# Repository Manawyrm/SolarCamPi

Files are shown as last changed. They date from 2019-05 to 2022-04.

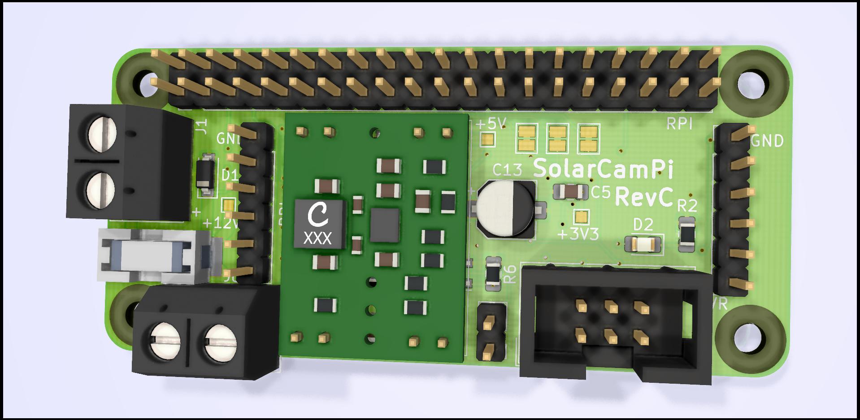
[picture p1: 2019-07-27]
pcb/solarcampi.jpg

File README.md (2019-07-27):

# SolarCamPi

__Detailed information at https://tbspace.de/solarcampi.html__

BOM (PCB-RevC):  
https://tbspace.de/content/downloads/ibom_solarcampi_revc.html

Firmware (PCB-RevB/RevC):  
https://github.com/Manawyrm/SolarCamPi/tree/master/firmware

Schematic (PCB-RevC):  
https://github.com/Manawyrm/SolarCamPi/blob/master/pcb/solarcampi.pdf

Raspberry Pi can flash the AVR, using [avrdude with LinuxSPI support](https://github.com/kcuzner/avrdude) and _inverted_ GPIO 17 as reset.

avrdude.conf configuration entry: 
```
programmer 
  id       = "linuxspi";
  desc     = "Use Linux SPI device in /dev/spidev*";
  type     = "linuxspi";
  reset    = ~ 17;
  baudrate = 40000;
;
```

avrdude Usage to flash firmware:  
`avrdude -p m328p -P /dev/spidev0.0 -c linuxspi -U flash:w:firmware.hex`
  
avrdude Usage to set fuses:  
`avrdude -p m328p -P /dev/spidev0.0 -c linuxspi -U lfuse:w:0xe2:m -U hfuse:w:0xd9:m -U efuse:w:0xfd:m`

Revision B PCB

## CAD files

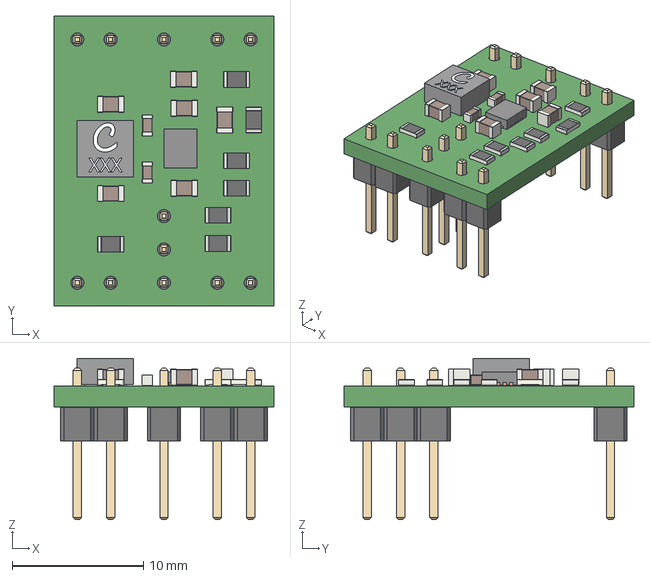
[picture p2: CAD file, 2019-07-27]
pcb/models/module-full.step
16.8 x 22.1 x 12.3 mm

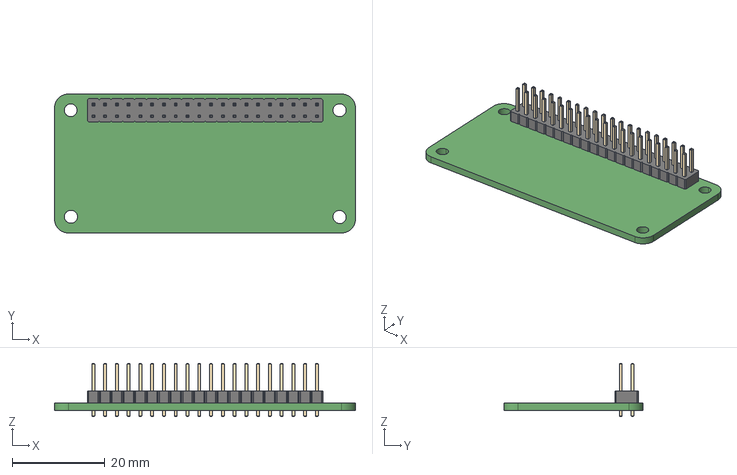
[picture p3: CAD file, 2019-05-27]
solarcampi/solarcampi.step
65.0 x 30.0 x 11.5 mm

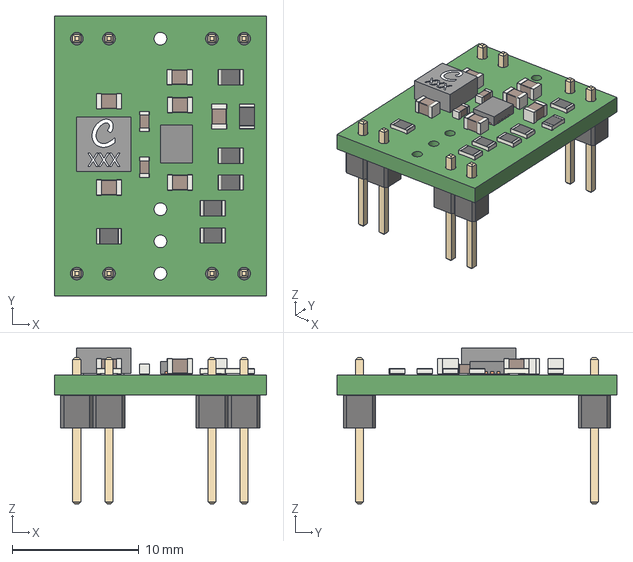
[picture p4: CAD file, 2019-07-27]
pcb/models/module-compat.step
16.8 x 22.1 x 12.3 mm

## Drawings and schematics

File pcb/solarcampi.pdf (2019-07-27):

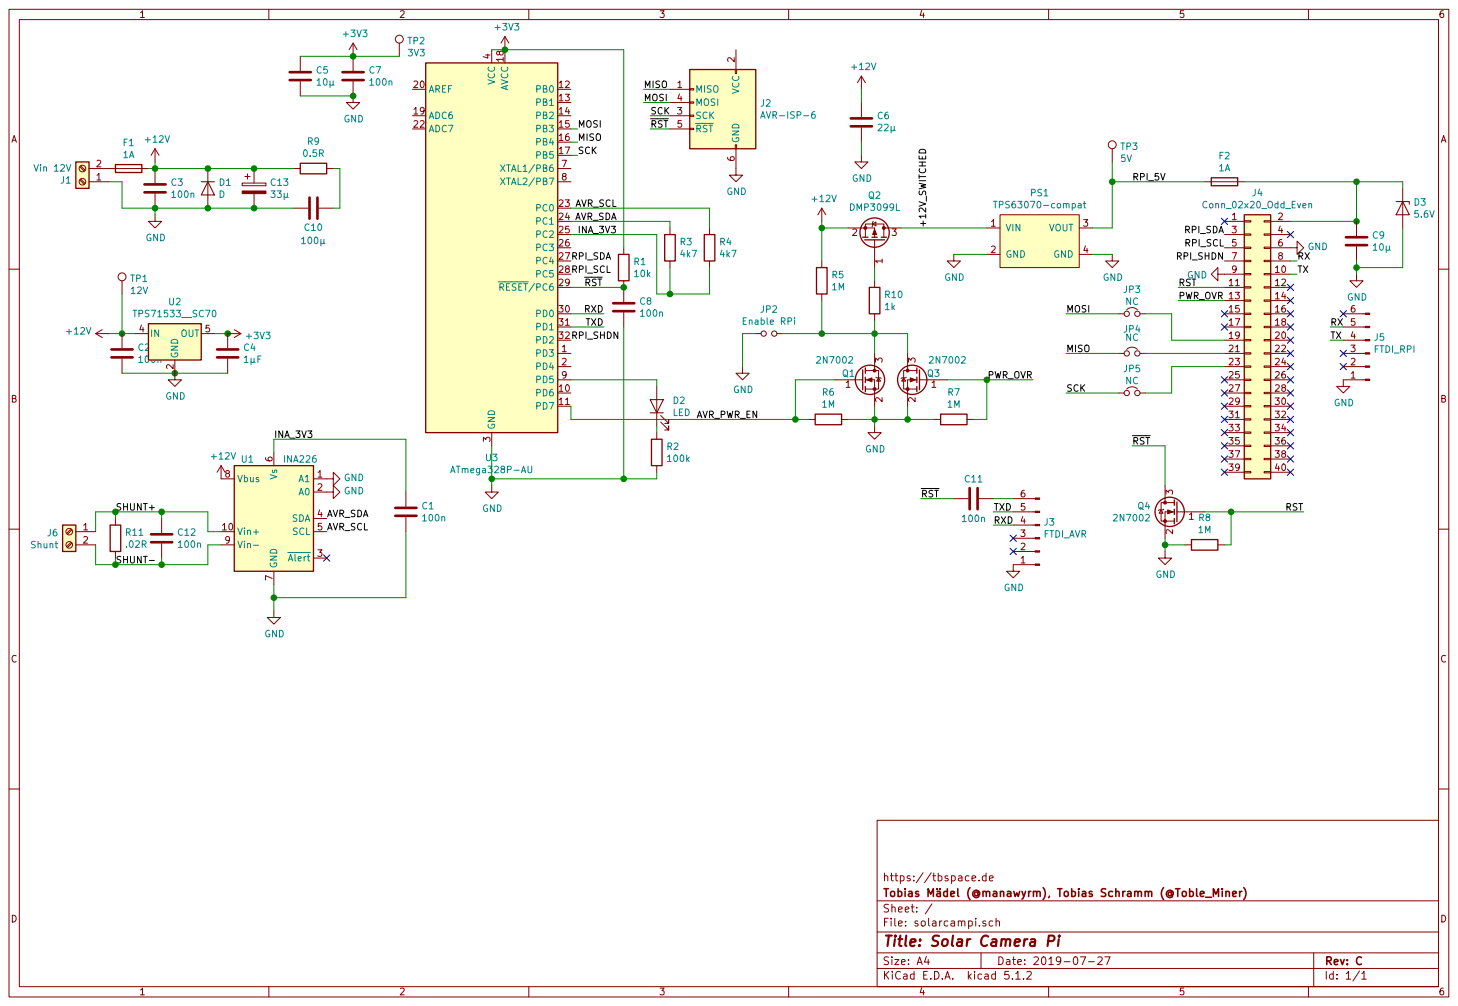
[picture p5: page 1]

2 SCK 3 MOSI 4 RST 5 GND
4k7GND

J2AVR-ISP-6 RST SCK MOSI MISO MOSI MISO

7 Vbus 8 Vin- 9 U1 INA226 SHUNT+ SHUNT- C12

https://tbspace.de
File: solarcampi.sch Sheet: / Tobias Mädel (@manawyrm), Tobias Schramm (@Toble_Miner)

Id: 1/1 Title: Solar Camera Pi

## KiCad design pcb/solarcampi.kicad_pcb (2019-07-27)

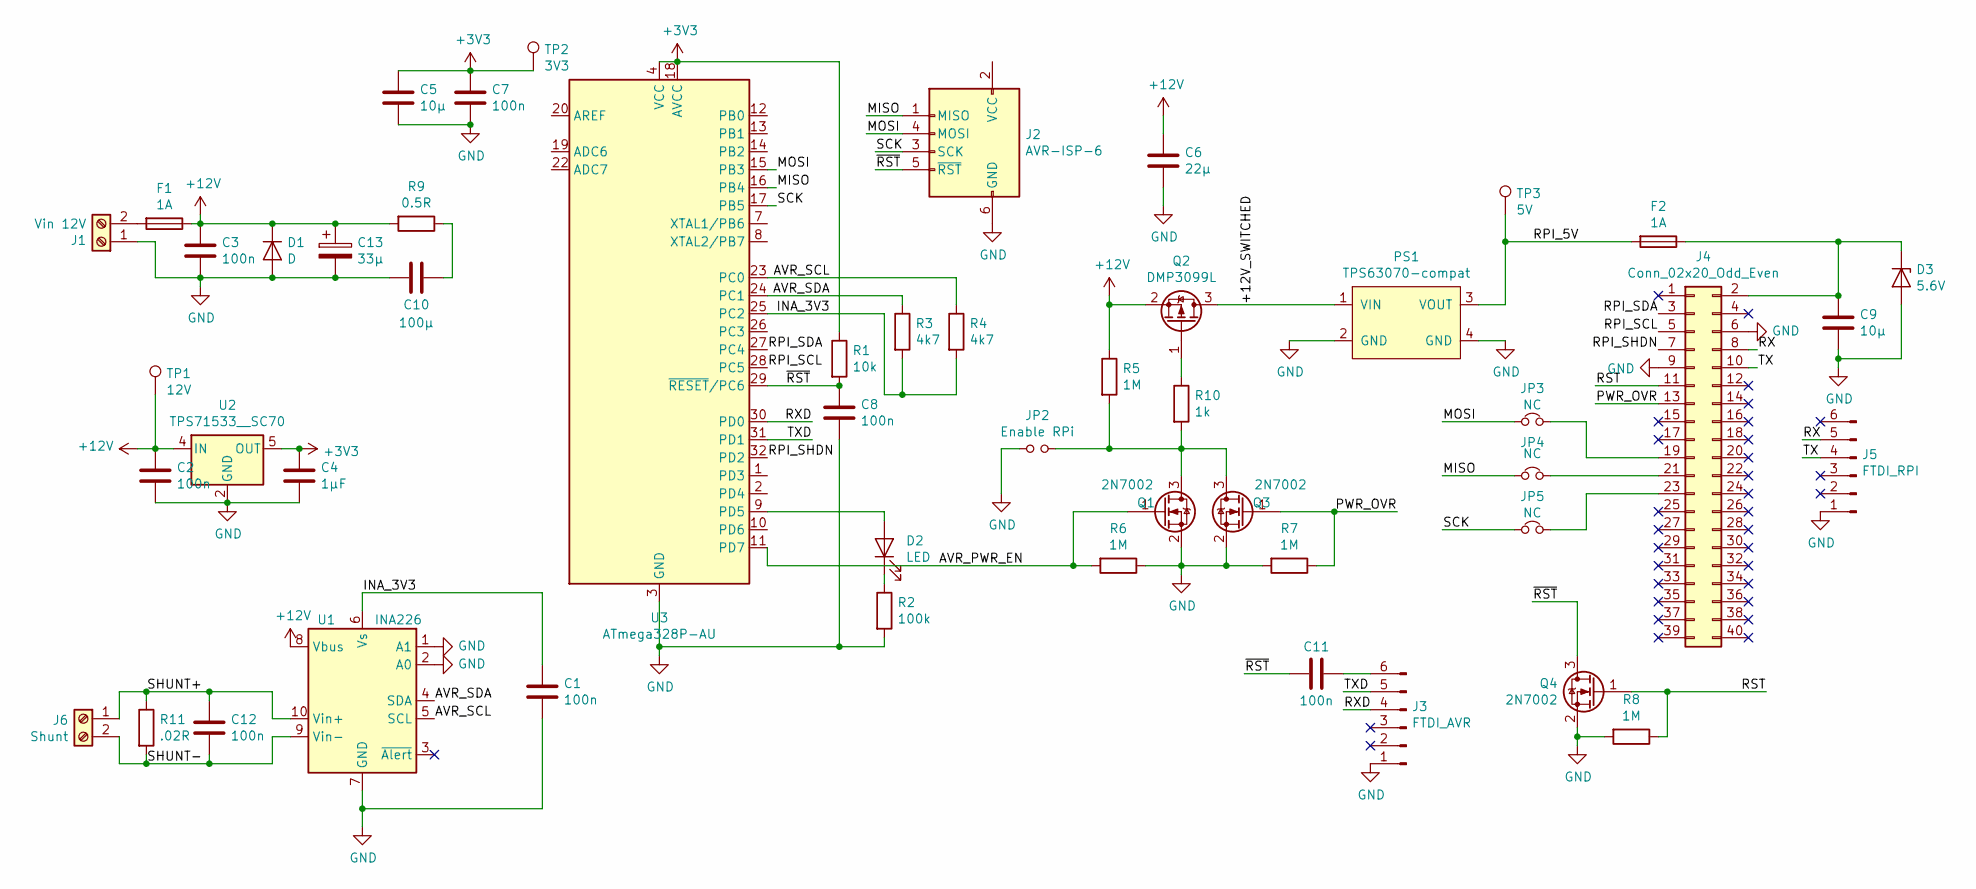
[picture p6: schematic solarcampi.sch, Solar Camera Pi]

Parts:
C1, C2, C3, C7, C8, C11, C12: 100n; C_0805_2012Metric_Pad1.15x1.40mm_HandSolder
C4: 1µF; C_0805_2012Metric_Pad1.15x1.40mm_HandSolder
C5, C9: 10µ; C_0805_2012Metric_Pad1.15x1.40mm_HandSolder
C6: 22µ; C_0805_2012Metric_Pad1.15x1.40mm_HandSolder
C10: 100µ; C_1210_3225Metric_Pad1.42x2.65mm_HandSolder
C13: 33µ; CP_Elec_5x5.4
D1: D; D_SOD-123
D2: LED; LED_0805_2012Metric_Pad1.15x1.40mm_HandSolder
D3: 5.6V; D_SOD-123
F1: 1A; Fuse_SMD_HASF
F2: 1A; Fuse_0805_2012Metric_Pad1.15x1.40mm_HandSolder
J1: Vin 12V; TerminalBlock_bornier-2_P5.08mm
J2: AVR-ISP-6; IDC-Header_2x03_P2.54mm_Vertical
J3: FTDI_AVR; PinHeader_1x06_P2.54mm_Vertical
J4: Conn_02x20_Odd_Even; PinHeader_2x20_P2.54mm_Vertical
J5: FTDI_RPI; PinHeader_1x06_P2.54mm_Vertical
J6: Shunt; TerminalBlock_bornier-2_P5.08mm
JP2: Enable RPi; PinHeader_1x02_P2.54mm_Vertical
JP3, JP4, JP5: NC; SolderJumper-2_P1.3mm_Bridged_Pad1.0x1.5mm
PS1: TPS63070-compat; TPS63070-module-compat
Q1, Q3, Q4: 2N7002; SOT-23
Q2: DMP3099L; SOT-23
R1: 10k; R_0805_2012Metric_Pad1.15x1.40mm_HandSolder
R2: 100k; R_0805_2012Metric_Pad1.15x1.40mm_HandSolder
R3, R4: 4k7; R_0805_2012Metric_Pad1.15x1.40mm_HandSolder
R5, R6, R7, R8: 1M; R_0805_2012Metric_Pad1.15x1.40mm_HandSolder
R9: 0.5R; R_1210_3225Metric_Pad1.42x2.65mm_HandSolder
R10: 1k; R_0805_2012Metric_Pad1.15x1.40mm_HandSolder
R11: .02R; R_1210_3225Metric_Pad1.42x2.65mm_HandSolder
TP1: 12V; TestPoint_Pad_1.0x1.0mm
TP2: 3V3; TestPoint_Pad_1.0x1.0mm
TP3: 5V; TestPoint_Pad_1.0x1.0mm
U1: INA226; MSOP-10_3x3mm_P0.5mm
U2: TPS71533__SC70; SOT-353_SC-70-5_Handsoldering
U3: ATmega328P-AU; TQFP-32_7x7mm_P0.8mm

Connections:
+3V3: C4.1, C5.1, C7.1, R1.1, TP2.1, U2.5 (OUT), U3.4 (VCC), U3.6 (VCC), U3.18 (AVCC)
+12V: C2.1, C3.1, C6.2, C13.1, D1.1 (K), F1.1, Q2.2 (S), R5.1, R9.2, TP1.1, U1.8 (Vbus), U2.4 (IN)
/+12V_SWITCHED: PS1.1 (VIN), Q2.3 (D)
/AVR_PWR_EN: Q1.1 (G), R6.2, U3.11 (PD7)
/AVR_SCL: R4.1, U1.5 (SCL), U3.23 (PC0)
/AVR_SDA: R3.1, U1.4 (SDA), U3.24 (PC1)
/INA_3V3: C1.1, R3.2, R4.2, U1.6 (Vs), U3.25 (PC2)
/MISO: J2.1 (MISO), JP4.1, U3.16 (PB4)
/MOSI: J2.4 (MOSI), JP3.1, U3.15 (PB3)
/PWR_OVR: J4.13, Q3.1 (G), R7.1
/RPI_5V: F2.2, PS1.3 (VOUT), TP3.1
/RPI_SCL: J4.5, U3.28 (PC5)
/RPI_SDA: J4.3, U3.27 (PC4)
/RPI_SHDN: J4.7, U3.32 (PD2)
/RST: J4.11, Q4.1 (G), R8.1
/RX: J4.8, J5.5
/RXD: J3.4, U3.30 (PD0)
/SCK: J2.3 (SCK), JP5.1, U3.17 (PB5)
/SHUNT+: C12.1, J6.1, R11.1, U1.10 (Vin+)
/SHUNT-: C12.2, J6.2, R11.2, U1.9 (Vin-)
/TX: J4.10, J5.4
/TXD: J3.5, U3.31 (PD1)
/~RST: C8.1, C11.2, J2.5 (~RST), Q4.3 (D), R1.2, U3.29 (~RESET~/PC6)
GND: C1.2, C2.2, C3.2, C4.2, C5.2, C6.1, C7.2, C8.2, C9.2, C10.1, C13.2, D1.2 (A), D3.2 (A), J1.1, J2.6 (GND), J3.1, J4.6, J4.9, J5.1, JP2.1, PS1.2 (GND), PS1.4 (GND), Q1.2 (S), Q3.2 (S), Q4.2 (S), R2.2, R6.1, R7.2, R8.2, U1.1 (A1), U1.2 (A0), U1.7 (GND), U2.2 (GND), U3.3 (GND), U3.5 (GND), U3.21 (GND)
unnamed: C9.1, D3.1 (K), F2.1, J4.2
unnamed: C10.2, R9.1
unnamed: C11.1, J3.6
unnamed: D2.1 (K), R2.1
unnamed: D2.2 (A), U3.9 (PD5)
unnamed: F1.2, J1.2
unnamed: J4.19, JP3.2
unnamed: J4.21, JP4.2
unnamed: J4.23, JP5.2
unnamed: JP2.2, Q1.3 (D), Q3.3 (D), R5.2, R10.2
unnamed: Q2.1 (G), R10.1

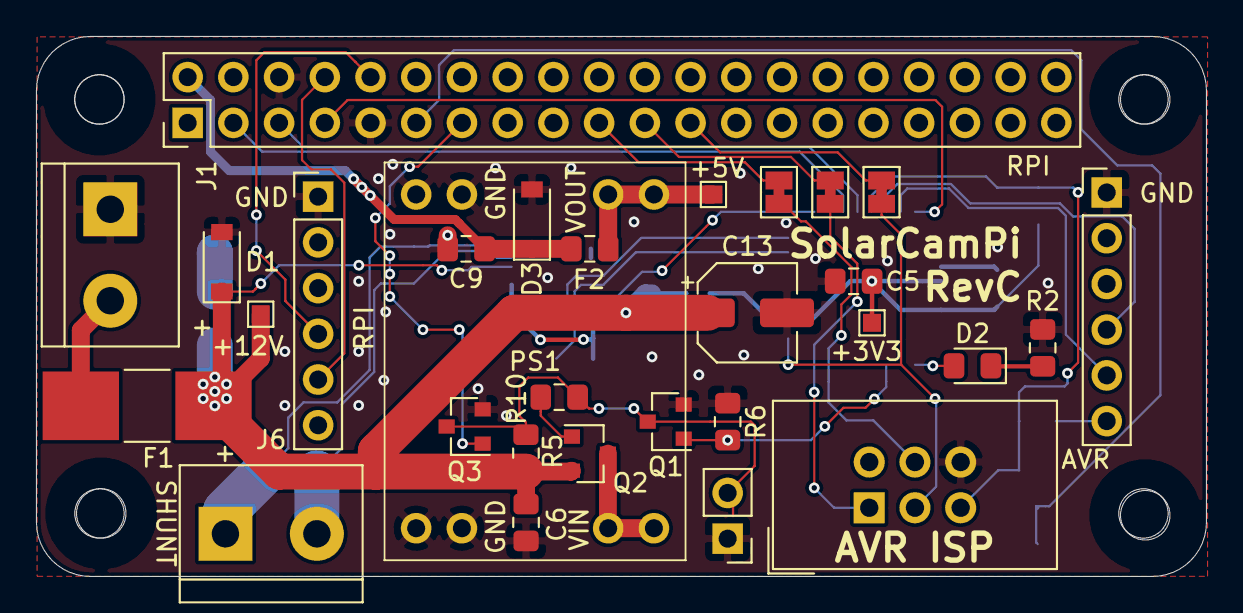
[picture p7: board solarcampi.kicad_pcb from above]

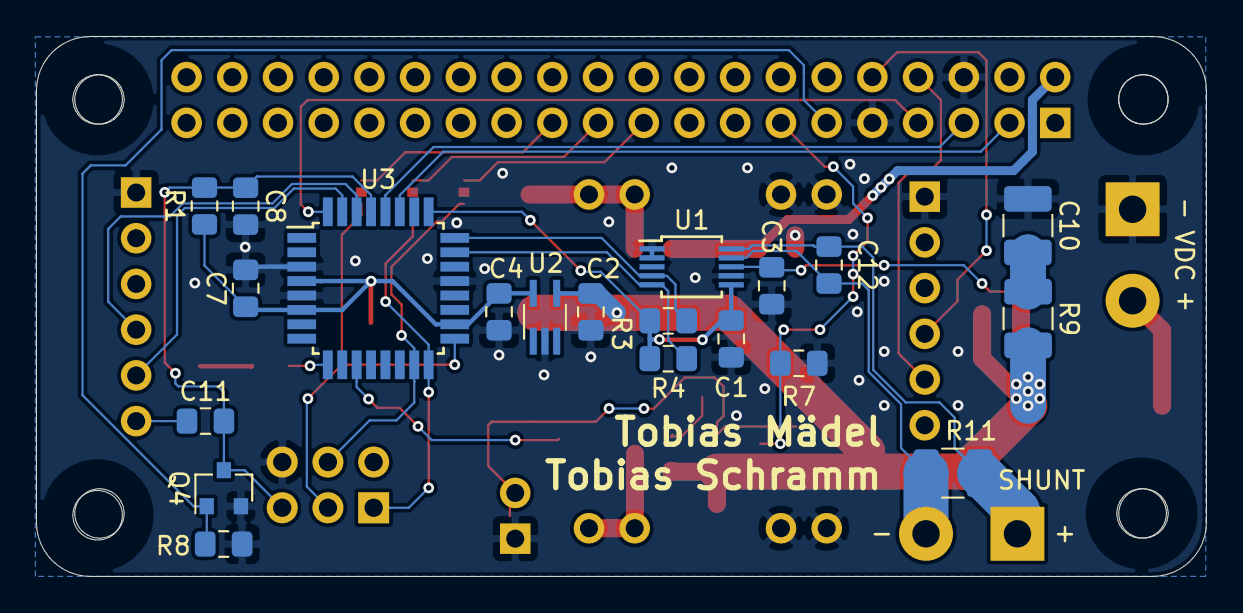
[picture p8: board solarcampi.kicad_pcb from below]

Board: 2 copper layers, 65.0 x 30.0 mm, 50 parts (20 on the bottom side), 35 nets.

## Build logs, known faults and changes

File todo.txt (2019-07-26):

Rev B Errata: 
SMD N-channel mosfet footprint is wrong, drain & source flipped
AVR UART header reset circuitry wrong
AVR UART header RX/TX flipped
Electrolytic caps on input against MLCC ringing missing
Test points/header for INA shunt

Rev A Errata: 
no test points for voltages ✓
no AVR UART header / test points ✓
missing debug/power LED 
bad TPS LDO placement causes EMI issues ✓
bad MOSFET choice (Vgs max 12V) ✓
bad SMPS choice (unstable, latchup issue and high inrush currents)
jumper for raspi enable ✓
optional: crowbar circuit to protect RPi  ✓
optional: reverse polarity protection on input  ✓

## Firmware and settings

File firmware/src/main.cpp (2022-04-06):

/*
@brief               Embedded controller for solar-powered webcam
@date                2022-04-03
@version             1.10
@author              Tobias Mädel
@license             MIT

@par 2019-05-26 Tobias Mädel Initial version
@par 2022-04-03 Tobias Mädel Added additional debug logs
*/
#include "main.h"
#include "config.h"
#include <SoftWire.h>
#include <Wire.h>
#include "Adafruit_INA219.h"
#include "LowPower.h"

volatile uint8_t state = STATE_ACTIVE; 
volatile uint8_t oldState = state;
uint16_t activeTime = 0; 
uint16_t currentSleepTime = 0; 

// INA220 Init
Adafruit_INA219 ina219;
SoftWire inaWire(AVR_SDA, AVR_SCL);
uint8_t txBuf[20];
uint8_t rxBuf[20];

// RPi I2C Slave
volatile uint8_t i2cRegister;
volatile uint8_t i2cData;

volatile uint8_t writeEEPROM = 0;

#define registers log_data 

#define debug_print(x) Serial.print(x); Serial.flush();
#define debug_println(x) Serial.println(x); Serial.flush();

void setup()
{
    pinMode(LED, OUTPUT); 
    digitalWrite(LED, 1); 

    Serial.begin(115200);
    debug_println("SolarCamPi Init");

    eeprom_init();
    if (!eeprom_find_log_block())
    {
        debug_println("Initializing EEPROM");
        log_data  = {
            .voltage = 0,
            .sleepIntervalFast = 50, // 280s
            .sleepIntervalSlow = 225, // 1800s
            .sleepIntervalSlowVoltage = 7000,
            .undervoltageLockout = 4000,
            .undervoltageHysteresis = 4500,
            .disableTimeout = 0,
            .timeout = 120,
            .current = 0,
            .lastTimestamp = 0
        };
        eeprom_write_log_block();
    }
    else
    {
        debug_println("Block found");
    }

    debug_print_registers();

    pinMode(RPI_SHDN, INPUT_PULLUP);
    pinMode(AVR_PWR_EN, OUTPUT); 
    pinMode(LED, OUTPUT); 

    debug_println("Trying to initialize INA");
    setINAState(HIGH);

    inaWire.enablePullups(false);
    inaWire.setTimeout_ms(200);
    inaWire.setClock(10000);
    inaWire.setRxBuffer(rxBuf, sizeof(rxBuf));
    inaWire.setTxBuffer(txBuf, sizeof(txBuf));

    ina219.begin(&inaWire);

    debug_println("Setting up RPI I2C");

    Wire.begin(8);
    Wire.onReceive(handleI2CReceive);
    Wire.onRequest(handleI2CRequest);
    
    attachInterrupt(digitalPinToInterrupt(RPI_SHDN), shutdownSignaled, FALLING);  
}

void loop()
{
    //debug_println("Reading from INA");
    registers.voltage = (ina219.getBusVoltage_V() * 1000.0f);
    registers.current = ina219.getCurrent_mA();
    //debug_println("Read from INA finish");
    //debug_print_registers();

    if (registers.voltage < registers.undervoltageLockout)
    {
        state = STATE_UNDERVOLTAGE;
    }

    if (writeEEPROM)
    {
        writeEEPROM = 0; 
        if (registers.disableTimeout)
        {
            registers.disableTimeout = 0;
            eeprom_write_log_block();
            while (eeprom_busy());
            registers.disableTimeout = 1;
        }
        else
        {
            Serial.println("eeprom write start");
            eeprom_write_log_block();
            Serial.println("eeprom write end");
        }
        debug_print_registers();
    }

    debug_print_state_change();
    switch (state)
    {
        case STATE_ACTIVE:
            digitalWrite(AVR_PWR_EN, HIGH); 
            digitalWrite(LED, HIGH);
            delay(500);
            if (!registers.disableTimeout)
                activeTime++;

            if (registers.timeout < activeTime)
            {
                debug_println("Timeout reached! Shutting down!");
                state = STATE_SLEEP; 
            }
            break;
        case STATE_SLEEP: 
            registers.disableTimeout = 0; 
            activeTime = 0;

            while (eeprom_busy());

            if (registers.voltage > registers.sleepIntervalSlowVoltage)
            {
                sleep(registers.sleepIntervalFast);
            }
            else
            {
                sleep(registers.sleepIntervalSlow);
            }
        
            state = STATE_ACTIVE;
            break;
        case STATE_UNDERVOLTAGE: 
            if (registers.voltage > registers.undervoltageHysteresis)
            {
                state = STATE_ACTIVE; 
            }
            else
            {
                sleep(registers.sleepIntervalFast);
            }
            break;
    }

}

void shutdownSignaled()
{
    if (state == STATE_ACTIVE)
        state = STATE_SLEEP; 
}

void handleI2CRequest()
{
    Wire.write(((uint8_t*)&registers)[i2cRegister]);
}
void handleI2CReceive(volatile int numBytes)
{
    Wire.write(0x80);
    if (numBytes == 1)
    {
        // i2cget -y 1 0x08 42 c
        i2cRegister = Wire.read();
    }
    if (numBytes == 2)
    {
        // i2cset -y 1 0x08 22 42 b
        i2cRegister = Wire.read();
        i2cData = Wire.read();

       /* Serial.print("Register: "); 
        Serial.println(i2cRegister);
        Serial.print("Data: "); 
        Serial.println(i2cData);*/

        if (sizeof(registers) > i2cRegister)
        {
            ((uint8_t*)&registers)[i2cRegister] = i2cData;
            
            if (i2cRegister != 12 && // Disable timeout flag
                i2cRegister != 17 && // Last timestamp
                i2cRegister != 18 && // Last timestamp
                i2cRegister != 19 && // Last timestamp
                i2cRegister != 20)   // Last timestamp  
                writeEEPROM = 1;
        }
    }
    while (Wire.available()>0){Serial.print(Wire.read(), HEX);}
}

void setINAState(bool state = LOW)
{
    pinMode(INA_3V3, OUTPUT);
    digitalWrite(INA_3V3, state);
}

void sleep(uint16_t sleepTime)
{
    debug_println("sleep()");

    setINAState(false); 

    digitalWrite(RPI_SHDN, LOW); 
    pinMode(RPI_SHDN, OUTPUT);

    digitalWrite(AVR_PWR_EN, LOW);
    digitalWrite(LED, LOW);

    Wire.end();

    while (currentSleepTime != sleepTime)
    {
        currentSleepTime++;
        LowPower.powerDown(SLEEP_8S, ADC_OFF, BOD_OFF); 
    }
    currentSleepTime = 0;

    pinMode(RPI_SHDN, INPUT_PULLUP);

    setINAState(true); 

    Wire.begin(8);
    Wire.onReceive(handleI2CReceive);
    Wire.onRequest(handleI2CRequest);

    debug_println("wakeup!");
}

void debug_print_state_change()
{
    if (oldState != state)
    {
        debug_print("[state] ");
        debug_print_state_name(oldState);
        debug_print(" -> ");
        debug_print_state_name(state);
        debug_println();

        oldState = state;
    }
}

void debug_print_state_name(uint8_t _state)
{
    switch (_state)
    {
        case STATE_ACTIVE: debug_print("STATE_ACTIVE"); break;
        case STATE_SLEEP: debug_print("STATE_SLEEP"); break;
        case STATE_UNDERVOLTAGE: debug_print("STATE_UNDERVOLTAGE"); break;
        default: debug_print("INVALID ("); debug_print(_state); debug_print(")") break;
    }
}

void debug_print_registers()
{
    debug_println("");
    debug_println("------------------------------");
    debug_print("Voltage: ");
    debug_println(registers.voltage);
    debug_print("sleepIntervalFast: ");
    debug_println(registers.sleepIntervalFast);
    debug_print("sleepIntervalSlow: ");
    debug_println(registers.sleepIntervalSlow);
    debug_print("sleepIntervalSlowVoltage: ");
    debug_println(registers.sleepIntervalSlowVoltage);
    debug_print("undervoltageLockout: ");
    debug_println(registers.undervoltageLockout);
    debug_print("undervoltageHysteresis: ");
    debug_println(registers.undervoltageHysteresis);
    debug_print("disableTimeout: ");
    debug_println(registers.disableTimeout);
    debug_print("timeout: ");
    debug_println(registers.timeout);
    debug_println("------------------------------");
    debug_println("");
}

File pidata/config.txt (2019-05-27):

# See /boot/overlays/README for all available options

gpu_mem=128
start_file=start_x.elf
fixup_file=fixup_x.dat
disable_camera_led=1

#initramfs initramfs-linux.img followkernel

dtoverlay=pi3-disable-bt
dtparam=audio=off
dtparam=act_led_trigger=none
dtparam=act_led_activelow=on

disable_splash=1
boot_delay=0

#force_turbo=1
#dtoverlay=sdtweak,overclock_50=100

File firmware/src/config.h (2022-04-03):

#pragma once

#define AVR_SCL 14 // INA220 Software I2C
#define AVR_SDA 15 // INA220 Software I2C
//#define AVR_I2C_PULLUP 20 // INA220 Software I2C
#define INA_3V3 16 // INA220 Power

#define AVR_PWR_EN 7 // MOSFET to enable RPi supply rail
#define RPI_SHDN 2   // Shutdown signalling from RPi
#define LED 5

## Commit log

2019-05-29 Add fuse, add decoupling caps, set footprints
    [SMD-HASF.stp, solarcampi.kicad_pcb, solarcampi.sch]
2019-05-30 Add ISP header, FTDI header, more caps, power switching for INA and 2 I2C busses
    [solarcampi.kicad_pcb, solarcampi.sch]
2019-05-31 Component placement v1
    [solarcampi.kicad_pcb, solarcampi.sch]
2019-05-31 Route everything
    [solarcampi.kicad_pcb, solarcampi.sch]
2019-05-31 RevA finished
    [SMD-HASF.stp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]
2019-06-06 add firmware
    [solarcampi-B_Cu.gbl, solarcampi-B_Mask.gbs, solarcampi-B_Paste.gbp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]
2019-06-06 rename firmware
    [solarcampi-B_Cu.gbl, solarcampi-B_Mask.gbs, solarcampi-B_Paste.gbp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]
2019-06-08 add timeout, voltage readback
2019-06-09 Fixed I2C Write
2019-06-09 fix I2C after sleep, update todo
    [main.cpp]
2019-06-16 Schematic RevB
    [solarcampi.kicad_pcb, solarcampi.sch]
2019-06-16 Layout RevB
    [solarcampi.kicad_pcb, solarcampi.sch]
2019-06-16 Add 2-pin screw terminal with 3d model
    [solarcampi.kicad_pcb]
2019-06-16 Minor aesthetic fixups
    [solarcampi.kicad_pcb]
2019-06-16 Add more GND pins to reduce GND loop area
    [solarcampi.kicad_pcb, solarcampi.sch]
2019-06-19 Widen throughholes for regulator footprint to 1 mm
    [solarcampi.kicad_pcb]
2019-06-19 Add pin headers to power module
    [solarcampi.kicad_pcb]
2019-07-24 Add interactive BOM
    [solarcampi.kicad_pcb]
2019-07-25 Firmware updated for RevB pcb
2019-07-26 Add charge current measurement
2019-07-26 Fix RevB errata
    - Fix SOT23 NMOS pinout
    - Fix AVR reset circuitry
    - Add ceramic snubber to suppress ringing at input
    [solarcampi.kicad_pcb, solarcampi.sch]
2019-07-26 Optimize GND around C11
    [solarcampi.kicad_pcb]
2019-07-27 Add current shunt
    [solarcampi.kicad_pcb, solarcampi.sch]
2019-07-27 Update 3d models
    [module-compat.step, module-full.step, solarcampi.kicad_pcb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]
2019-07-27 Update revision indictor to `RevC`
    [solarcampi.kicad_pcb]
2019-07-27 Add big electrolytic cap for further suppression of ringing
    [solarcampi.kicad_pcb, solarcampi.sch]
2019-07-27 Optimize GND connectivity
    [solarcampi.kicad_pcb]
2019-07-27 Finishing touches on RevC
    [solarcampi-B_Cu.gbl, solarcampi-B_Mask.gbs, solarcampi-B_Paste.gbp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]
